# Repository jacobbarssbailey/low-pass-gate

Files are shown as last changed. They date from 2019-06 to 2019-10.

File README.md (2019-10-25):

# Dual low pass gate

This project provides tested plans for a 8HP Eurorack-format Dual Low Pass Gate.

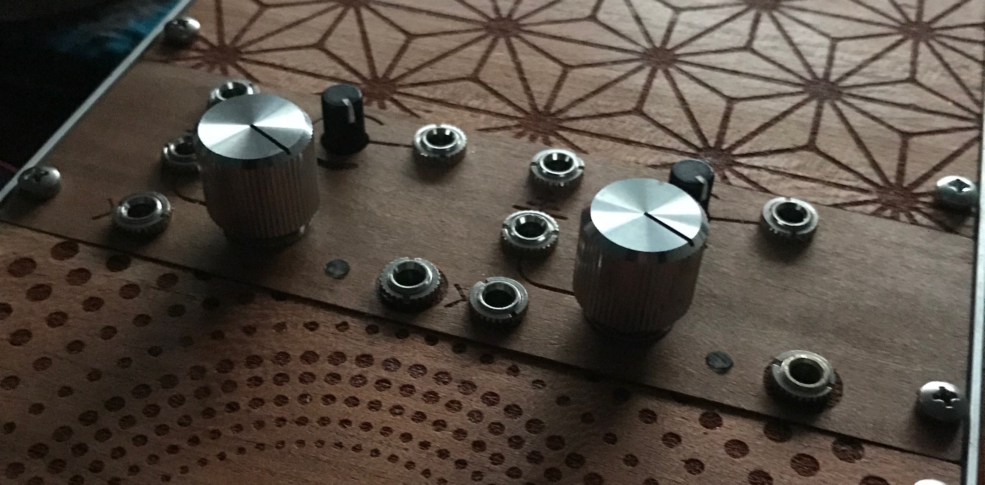
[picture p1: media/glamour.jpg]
Assembled module


## BOM

| Qty | Device | Value | Package | Parts | Notes |
| --- | --- | ----- | --- | ----- | ----- |
| 8 | Resistor | 1K | 0603 | R7, R11, R15, R24, R28, R32 | |
| 2 | Resistor | 4.7K | 0603 | R9, R27 | |
| 4 | Resistor | 47K | 0603 | R13, R17, R30, R34 | |
| 4 | Resistor | 10K | 0603 | R4, R14, R20, R31 | |
| 4 | Resistor | 100K | 0603 | R8, R16, R25, R33 | |
| 12 | Resistor | 200K | 0603 | R1, R2, R3, R5, R10, R12, R18, R19, R21, R22, R26, R29 | |
| 2 | Capacitor | 100p | 0603 | C3, C12 | |
| 2 | Capacitor | 560p | 0603 | C21, C22 | |
| 2 | Capacitor | 1.5n | 0603 | C4, C13 | |
| 8 | Capacitor | 100n | 0603 | C1, C5, C6, C8, C10, C15, C16, C19 | |
| 2 | Capacitor | 1µ | 0603 | C2, C11 | |
| 2 | Capacitor (Pol) | 47µ–100µ | Panasonic D | C14, C18 | |
| 4 | Pot | 100K | ALPS 9mm Vert | GAIN1, GAIN2, RMUTE1, RMUTE2 | |
| 10 | Audio Jack (Mono) |  | Inline | CTRL1, CTRL2, IN1, IN2, MUTE1, MUTE2, OUT1, OUT2, PLK1, PLK2 | [Erthenvar](https://erthenvar.myshopify.com/collections/accessories/products/3-5mm-inline-jacks) and others |
| 2 | Quad Op Amp | TL074 | SO14 | U1, U2 |  |
| 2 | Comparator | LM397 | SOT23-5 | IC2, IC5 |  |
| 8 | Schottky Diode |  | SOD323 | D1, D2, D3, D4, D5, D6, D7, D8 |  |
| 6 | Light Dependent Resistor | SR32-SR3 | VTL5C-SMALL | LDR1, LDR2, LDR3, LDR4, LDR5, LDR6 | [digikey.com](https://www.digikey.com/product-detail/en/advanced-photonix/NSL-32SR3/NSL-32SR3-ND/5039793) and others |
| 1 | 10 pin Power |  | 10 pin shrouded IDC 2.54mm pitch | P1 |  |
| 2 | LED[†](#leds) |  | 3mm | LED1, LED2 |  |

#### †LEDs
In the drive circuit, indicator LEDs and LDRs are driven in series, with identical current. For best results, use LEDs that have a acceptable brightness when driven in the range 0mA – 12mA.

### Assembly [important!]

The pairs of jacks IN1 & CTRL1 and IN2 & CTRL2 share a ground pin connection. Make sure to check CTRL1 and CTRL2 orientation before soldering.

## Operation and Controls

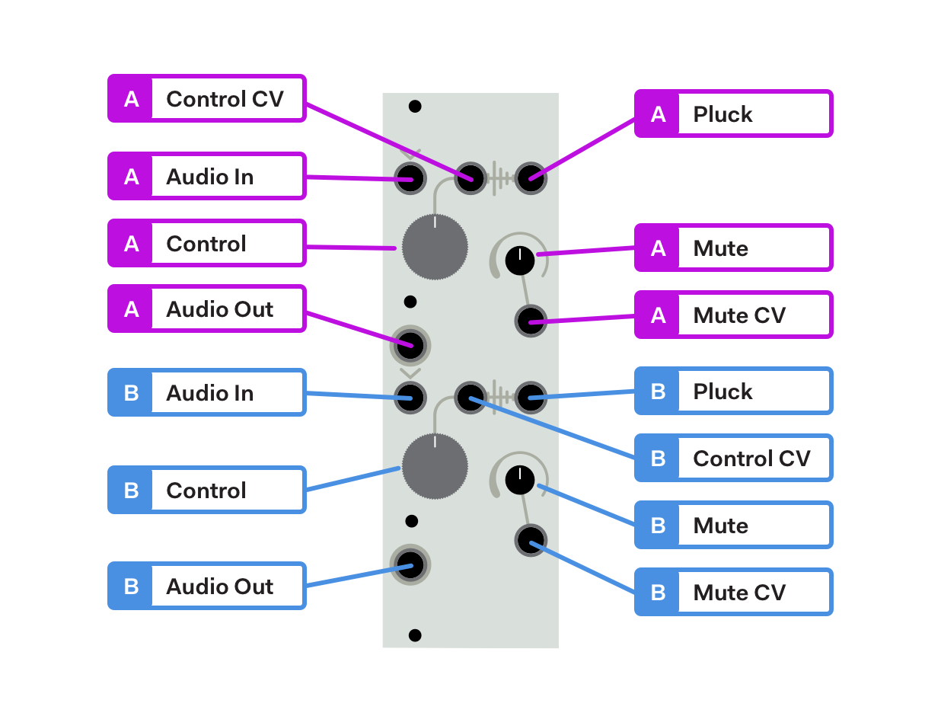
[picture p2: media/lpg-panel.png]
Panel with labels


Each channel of the gate/filter is identical, save that Channel B's Audio Input is normalled to Channel A's.

 The control knob opens the filter and allows audio to pass. It attenuates the Control CV (normalled to =6V).

Pluck CV is a gate-to-trigger converter feeding the control circuit. Gate signals sent to this input will 'pluck' the control circuit, causing it to ring out.

 The mute input (normalled to =10V) will both shorten the response time of the filter, and apply a very mild hi-pass filter. In a musical sense, its effect on the filter is akin to softly holding a palm against a rung bell or plucked string.

 At very low values, near 0V the mute input will allow some audio to pass through the circuit without any control input. If this isn't desired, turn the mute knob up to 15-20%.

## Other notes

Increasing the capacitance of C21 and C22 will increase the resonance of the low pass filter. Quite strong filter resonance is achievable by changing this component value.

Other LDRs/Vactrols may work equally well. If test any and have particular recommendations, please open an issue here.

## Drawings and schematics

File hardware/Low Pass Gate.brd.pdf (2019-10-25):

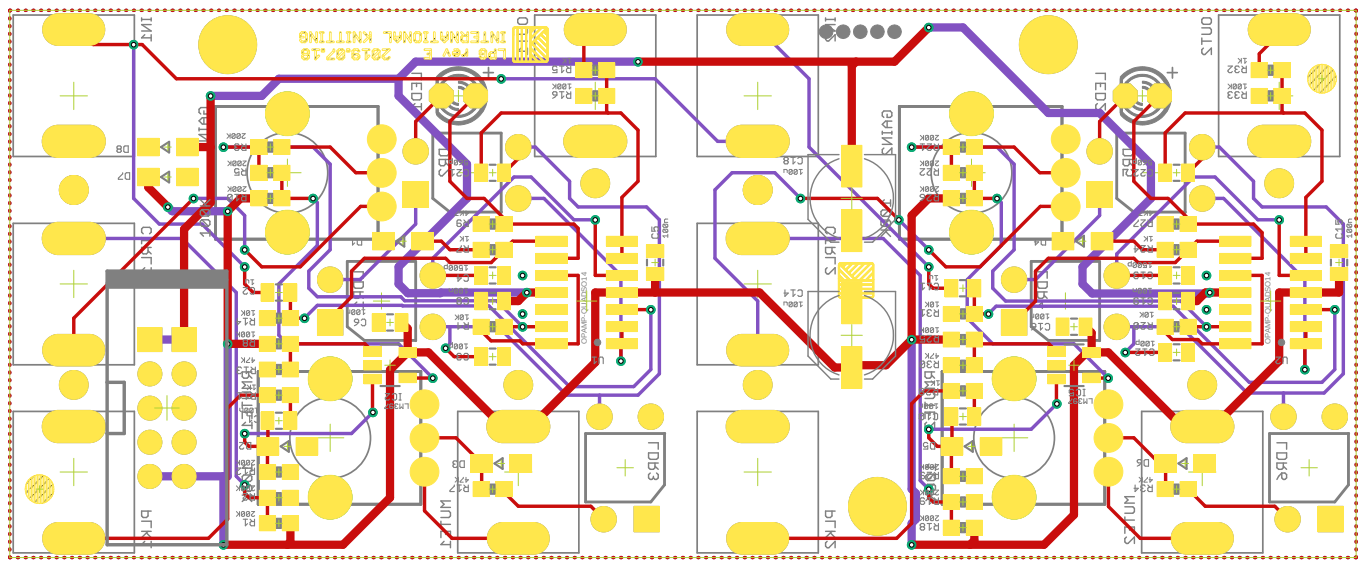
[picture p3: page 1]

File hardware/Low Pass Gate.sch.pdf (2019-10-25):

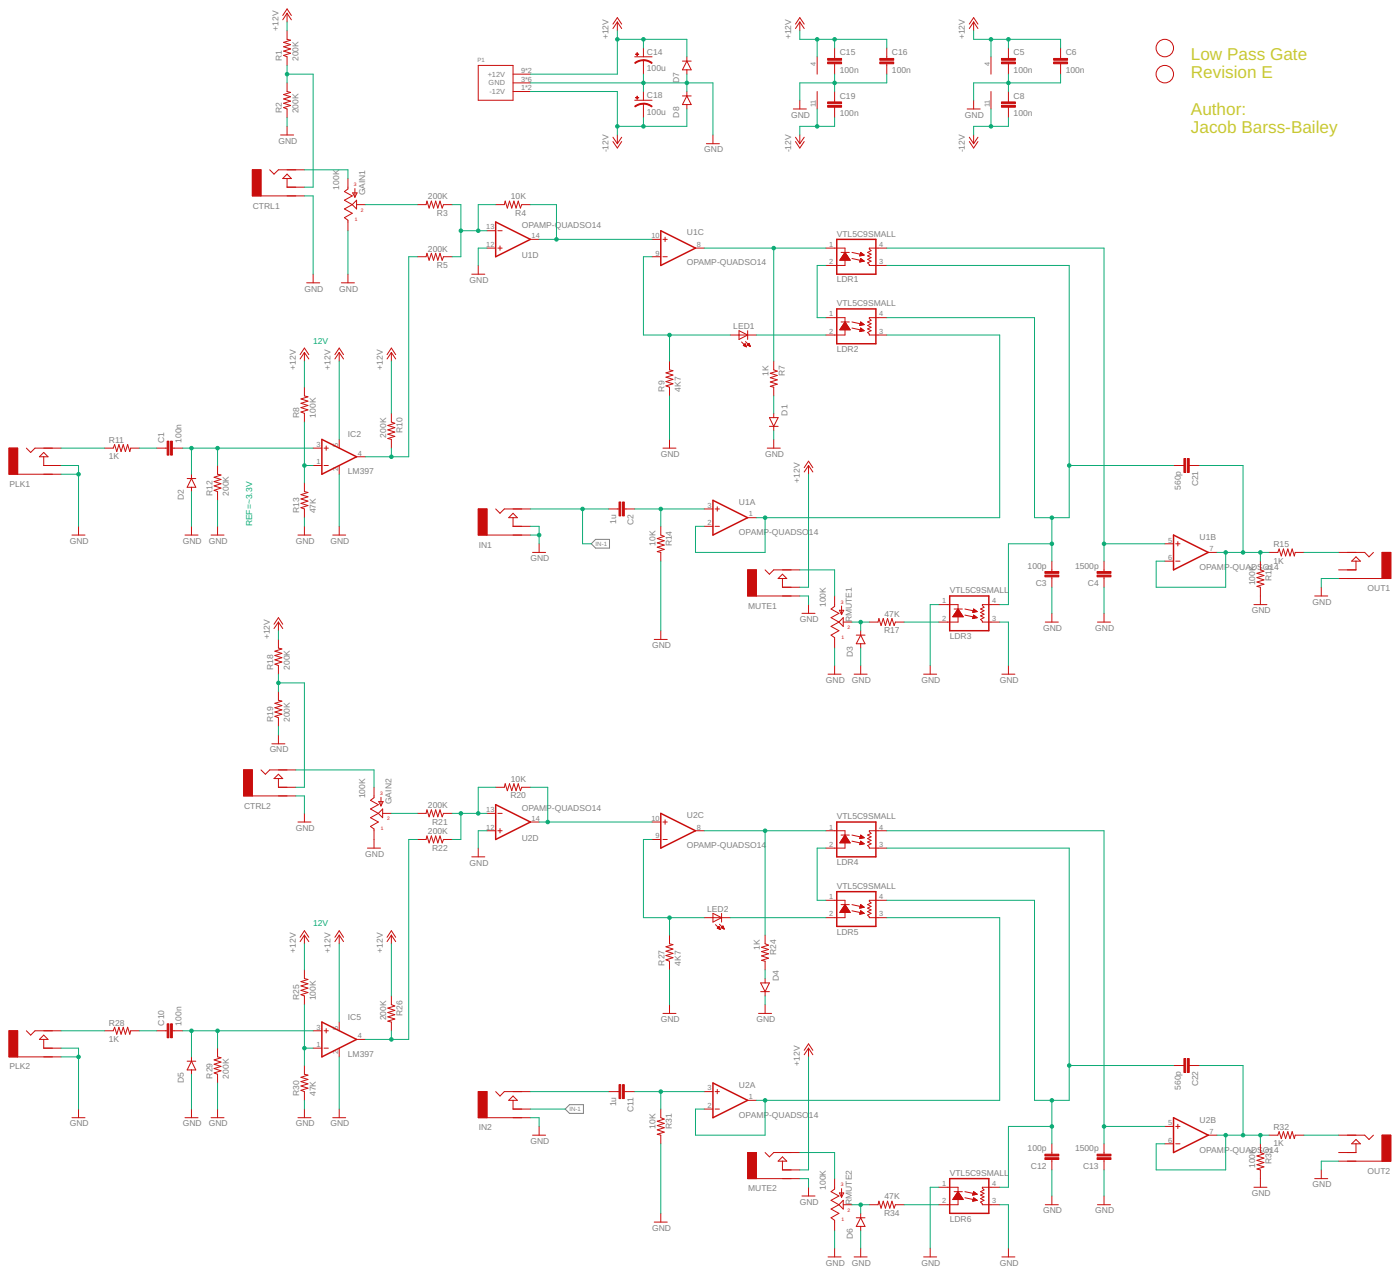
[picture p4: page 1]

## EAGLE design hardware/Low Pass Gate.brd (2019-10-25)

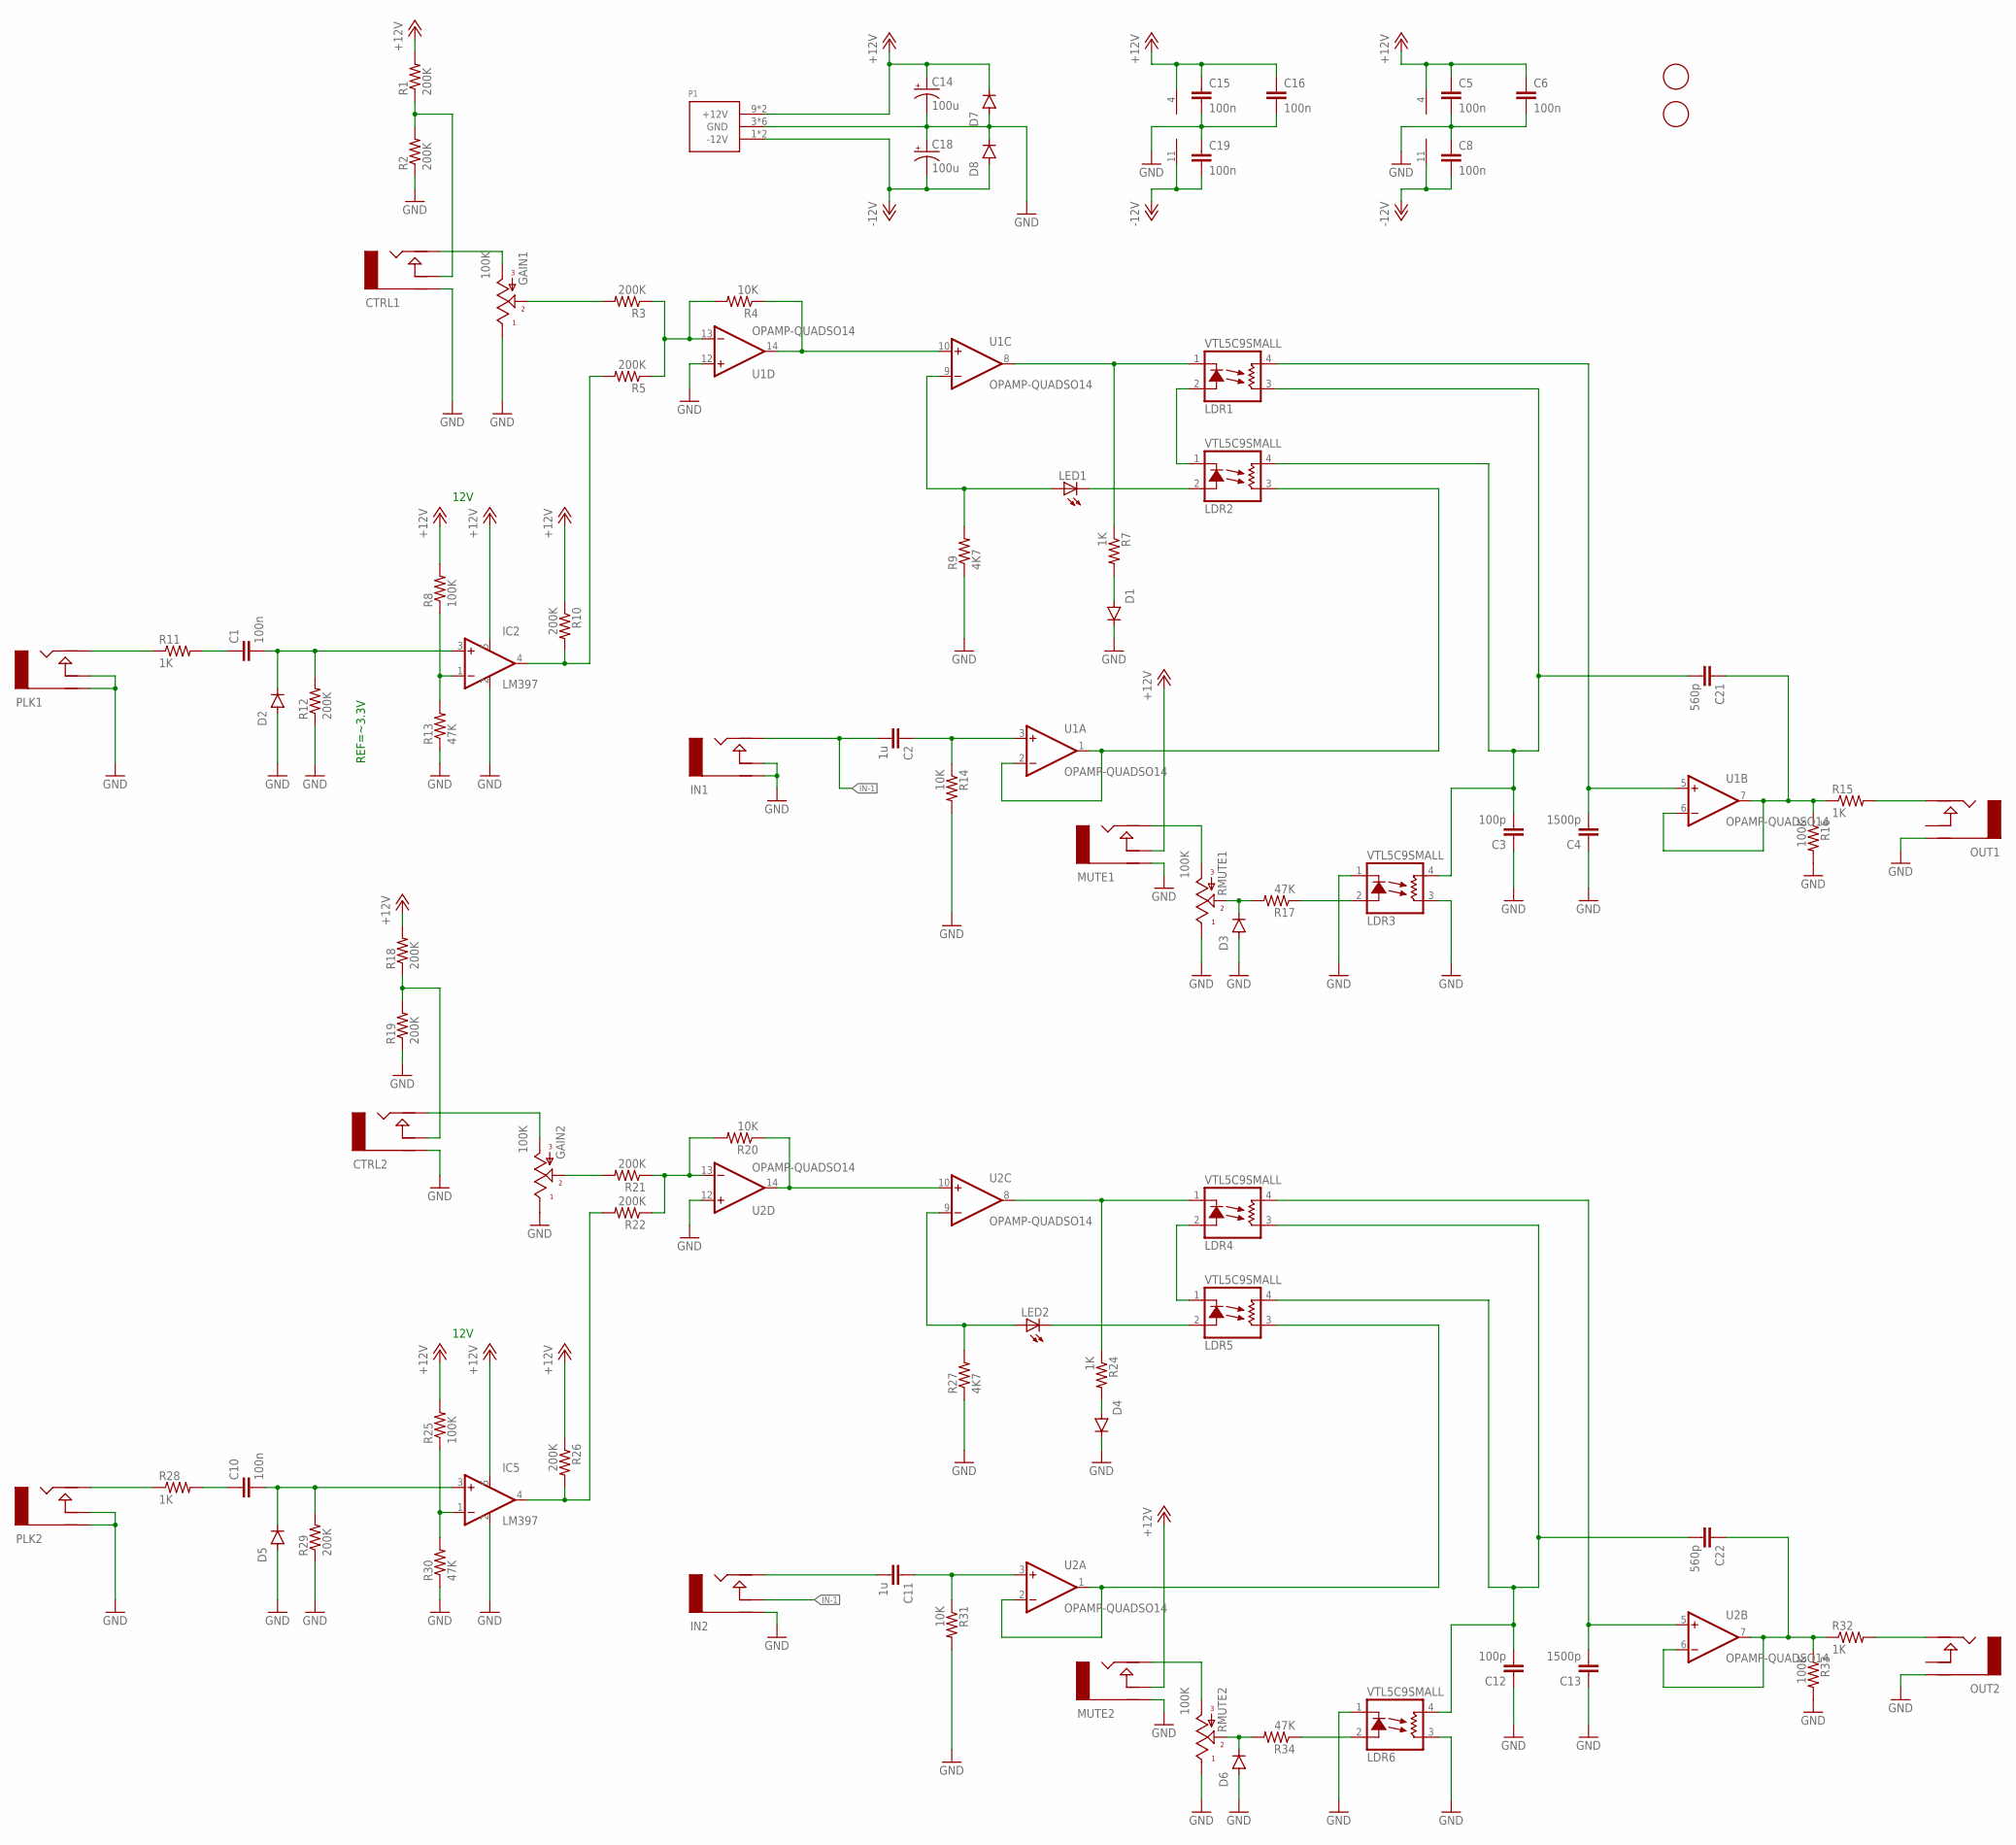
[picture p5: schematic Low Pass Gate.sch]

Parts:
C1, C5, C6, C8, C10, C15, C16, C19: 100n; 0805
C2, C11: 1u; 0805
C3, C12: 100p; 0805
C4, C13: 1500p; 0805
C14, C18: 100u; PANASONIC_D
C21, C22: 560p; 0805
CTRL1, CTRL2: AUDIO-JACKINLINE-FLOATGND; ERTHENVAR-JACK-INLINE-SHAREGND550
D1, D2, D3, D4, D5, D6, D7, D8: DIODE-SOD323-W; SOD323-W
GAIN1, GAIN2: 100K; ALPS_POT_KIT
IC2, IC5: LM397; SOT23-5
IN1, IN2: AUDIO-JACKINLINE-FLOATGND; ERTHENVAR-JACK-INLINE-SHAREGND550
LDR1, LDR2, LDR3, LDR4, LDR5, LDR6: VTL5C9SMALL; VTL5C-SMALL
LED1, LED2: LED3MM
MUTE1, MUTE2: AUDIO-JACKINLINE; ERTHENVAR-JACK-INLINE
OUT1, OUT2: AUDIO-JACKINLINE; ERTHENVAR-JACK-INLINE
P1: POWER_SIMPLE10_SHROUDED; POWER_10_SHROUDED
PLK1, PLK2: AUDIO-JACKINLINE; ERTHENVAR-JACK-INLINE
R1, R2, R3, R5, R10, R12, R18, R19, R21, R22, R26, R29: 200K; 0603-RES
R4, R14, R20, R31: 10K; 0603-RES
R7, R11, R15, R24, R28, R32: 1K; 0603-RES
R8, R16, R25, R33: 100K; 0603-RES
R9, R27: 4K7; 0603-RES
R13, R17, R30, R34: 47K; 0603-RES
RMUTE1, RMUTE2: 100K; ALPS_POT_KIT
U1, U2: OPAMP-QUADSO14; SO14
U$1, U$2: FIDUCIAL; FIDUCIAL_1MM

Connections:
+12V: C5.1, C6.1, C14.+, C15.1, C16.1, D7.C, IC2.5 (V+), IC5.5 (V+), MUTE1.N (NORM), MUTE2.N (NORM), P1.9 (+12V), P1.10 (+12V), R1.2, R8.2, R10.1, R18.2, R25.2, R26.1, U1.4 (VCC), U2.4 (VCC)
-12V: C8.2, C18.-, C19.2, D8.A, P1.1 (-12V), P1.2 (-12V), U1.11 (VEE), U2.11 (VEE)
GND: C3.1, C4.1, C5.2, C6.2, C8.1, C12.1, C13.1, C14.-, C15.2, C16.2, C18.+, C19.1, CTRL1.G (RING), CTRL2.G (RING), D1.C, D2.A, D3.A, D4.C, D5.A, D6.A, D7.A, D8.C, GAIN1.P$1 (E), GAIN2.P$1 (E), IC2.2 (GND), IC5.2 (GND), IN1.G (RING), IN1.N (NORM), IN2.G (RING), LDR3.1 (C), LDR3.3 (L1), LDR6.1 (C), LDR6.3 (L1), MUTE1.G (RING), MUTE2.G (RING), OUT1.G (RING), OUT2.G (RING), P1.3 (GND), P1.4 (GND), P1.5 (GND), P1.6 (GND), P1.7 (GND), P1.8 (GND), PLK1.G (RING), PLK1.N (NORM), PLK2.G (RING), PLK2.N (NORM), R2.1, R9.1, R12.1, R13.1, R14.2, R16.2, R19.1, R27.1, R29.1, R30.1, R31.2, R33.2, RMUTE1.P$1 (E), RMUTE2.P$1 (E), U1.12 (+IN), U2.12 (+IN)
IN-1: C2.2, IN1.T (TIP), IN2.N (NORM)
unnamed: R20.2, R21.1, R22.1, U2.13 (-IN)
unnamed: LDR4.1 (C), R24.1, U2.8 (OUT)
unnamed: LDR4.2 (A), LDR5.1 (C)
unnamed: GAIN2.P$2 (S), R21.2
unnamed: LED2.A, R27.2, U2.9 (-IN)
unnamed: LDR5.2 (A), LED2.K (C)
unnamed: CTRL2.N (NORM), R18.1, R19.2
unnamed: CTRL1.T (TIP), GAIN1.P$3 (A)
unnamed: D4.A, R24.2
unnamed: CTRL2.T (TIP), GAIN2.P$3 (A)
unnamed: PLK2.T (TIP), R28.1
unnamed: C11.2, IN2.T (TIP)
unnamed: IC5.4 (OUT), R22.2, R26.2
unnamed: C10.2, D5.C, IC5.3 (+IN), R29.2
unnamed: C10.1, R28.2
unnamed: IC5.1 (-IN), R25.1, R30.2
unnamed: R3.1, R4.2, R5.1, U1.13 (-IN)
unnamed: CTRL1.N (NORM), R1.1, R2.2
unnamed: IC2.4 (OUT), R5.2, R10.2
unnamed: D6.C, R34.2, RMUTE2.P$2 (S)
unnamed: OUT2.T (TIP), R32.2
unnamed: C11.1, R31.1, U2.3 (+IN)
unnamed: C13.2, LDR4.4 (L2), U2.5 (+IN)
unnamed: C1.2, D2.C, IC2.3 (+IN), R12.2
unnamed: LDR5.3 (L1), U2.1 (OUT), U2.2 (-IN)
unnamed: C22.1, R32.1, R33.1, U2.6 (-IN), U2.7 (OUT)
unnamed: C1.1, R11.2
unnamed: LDR6.2 (A), R34.1
unnamed: C12.2, C22.2, LDR4.3 (L1), LDR5.4 (L2), LDR6.4 (L2)
unnamed: IC2.1 (-IN), R8.1, R13.2
unnamed: PLK1.T (TIP), R11.1
unnamed: MUTE2.T (TIP), RMUTE2.P$3 (A)
unnamed: D1.A, R7.2
unnamed: OUT1.T (TIP), R15.2
unnamed: C2.1, R14.1, U1.3 (+IN)
unnamed: C4.2, LDR1.4 (L2), U1.5 (+IN)
unnamed: LDR2.3 (L1), U1.1 (OUT), U1.2 (-IN)
unnamed: C21.1, R15.1, R16.1, U1.6 (-IN), U1.7 (OUT)
unnamed: C3.2, C21.2, LDR1.3 (L1), LDR2.4 (L2), LDR3.4 (L2)
unnamed: MUTE1.T (TIP), RMUTE1.P$3 (A)
unnamed: LDR3.2 (A), R17.1
unnamed: LDR2.2 (A), LED1.K (C)
unnamed: LDR1.1 (C), R7.1, U1.8 (OUT)
unnamed: LDR1.2 (A), LDR2.1 (C)
unnamed: D3.C, R17.2, RMUTE1.P$2 (S)
unnamed: GAIN1.P$2 (S), R3.2
unnamed: LED1.A, R9.2, U1.9 (-IN)
VSIG: R20.1, U2.10 (+IN), U2.14 (OUT)
VSIG1: R4.1, U1.10 (+IN), U1.14 (OUT)

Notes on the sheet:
12V
REF=~3.3V

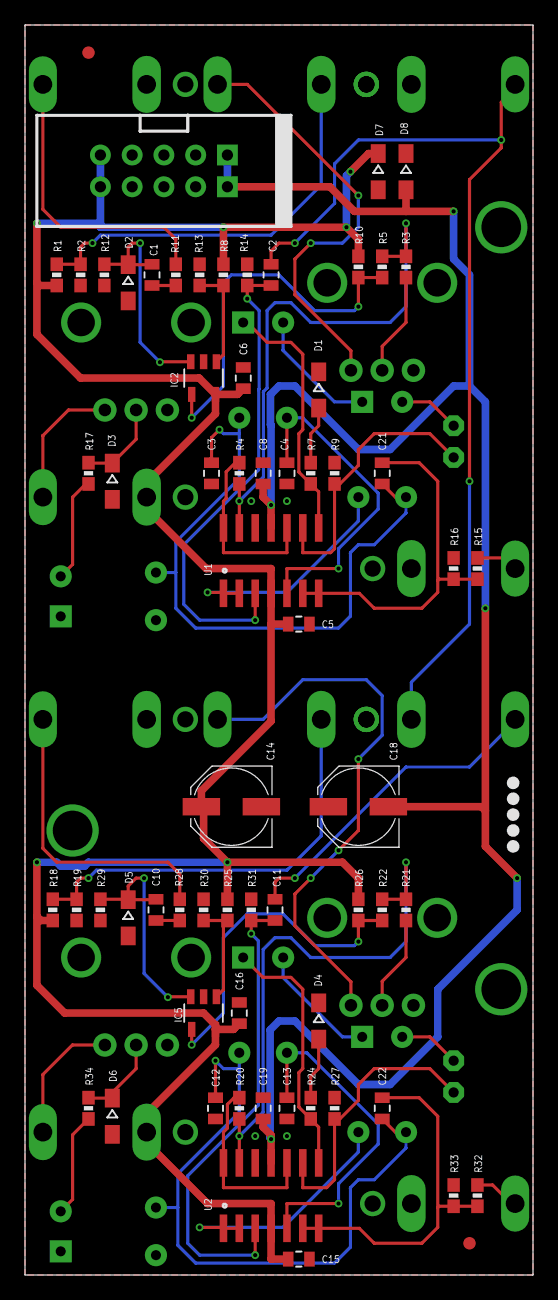
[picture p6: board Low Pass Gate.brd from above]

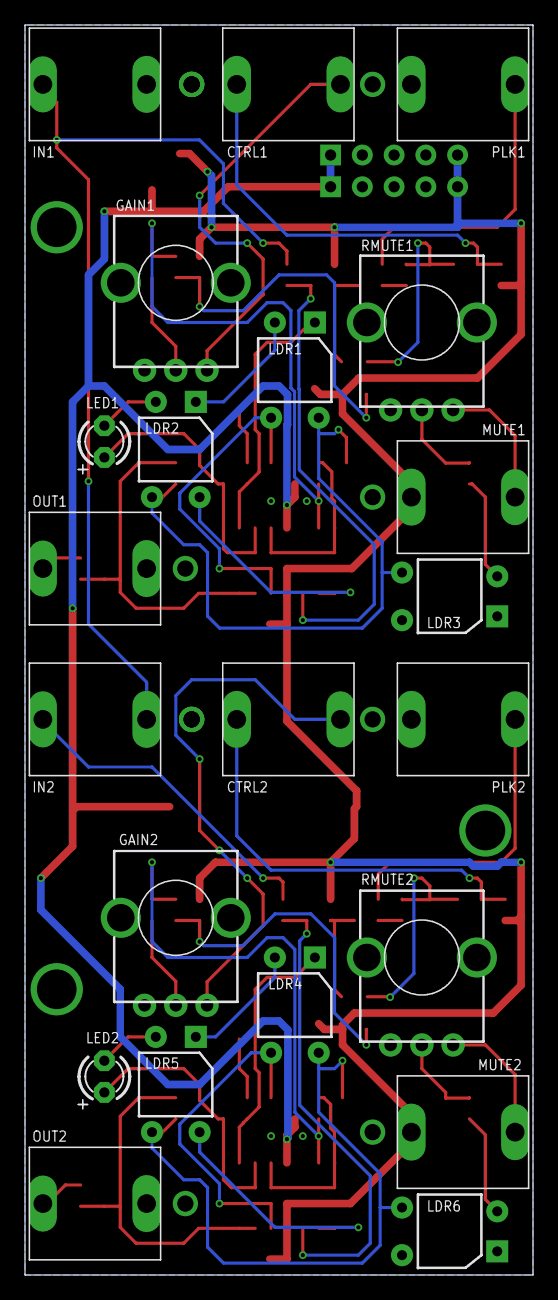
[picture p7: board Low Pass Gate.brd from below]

Board: 2 copper layers, 40.6 x 100.0 mm, 87 parts (22 on the bottom side), 53 nets.

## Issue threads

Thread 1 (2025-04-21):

Mute jacks on Dual Low Pass Gate.

OryH, 2025-04-21:
Hi! I built two of your dual LPG modules and I’m running into an issue with the mute jacks. When I plug in a cable, it causes a short and blows components. I noticed the mute input is normalled to +10V — should this be a switching jack, or am I wiring it incorrectly? Any clarification would be super helpful. It was running for a moment until i tried using the mutes.

Thank you ,
Ory H.

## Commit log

2019-06-23 add test fixture alignment holes
    [Low Pass Gate.brd]
2019-06-24 use throughhole bulk caps
    [Low Pass Gate.brd, Low Pass Gate.sch]
2019-06-24 fix power connector location for keyed connector width
    [Low Pass Gate.brd]
2019-07-09 revert to using ldr muting circuit
    [Low Pass Gate.brd, Low Pass Gate.sch]
2019-07-28 update to rev E
    [Low Pass Gate.brd, Low Pass Gate.sch]
2019-07-29 updated BOM for rev E
    [Low Pass Gate.brd, Low Pass Gate.sch]
2019-07-29 .gitignore fix
    [Low Pass Gate BOM.csv]
2019-07-29 hardware cleanup
    [Low Pass Gate BOM.csv]
2019-07-31 media diagrams, pdfs, clean up schm
    [Low Pass Gate.sch, Panel-alt.brd, Panel-alt.sch]
2019-09-17 update docs to mention audio pass through at low mute voltages
2019-09-18 fix C4/C13 value (that was resulting in 5.6x f(c) in filter)
    [Low Pass Gate.brd, Low Pass Gate.sch]
2019-09-19 Additional fix for C4/C13 value causing audio bleedthrough at low mute settings
    [Low Pass Gate.brd, Low Pass Gate.sch]
2019-09-25 adjust led drive current resistor
    [Low Pass Gate.brd, Low Pass Gate.sch]
2019-10-25 fix drive resistor value
    [Low Pass Gate.brd, Low Pass Gate.sch]

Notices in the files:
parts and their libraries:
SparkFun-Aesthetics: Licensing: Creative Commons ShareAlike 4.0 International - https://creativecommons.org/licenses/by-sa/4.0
